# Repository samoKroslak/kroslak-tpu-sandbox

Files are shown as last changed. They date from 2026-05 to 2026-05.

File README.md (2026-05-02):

# Quickstart

## First run (one-time setup)

```bash
cd kroslak-tpu
python -m venv .venv
.venv\Scripts\activate          # Windows
# source .venv/bin/activate     # Linux/Mac
pip install -r requirements.txt
python generate.py              # default 100×90×15 mm armrest
python generate.py --matrix     # 2×2 comparison plate
```

Output goes to `./out/` as paired `.3mf` and `.stl` files. The 3MF is what you load in Bambu Studio.

## Vibe-coding patterns with Claude Code

Open this folder in Claude Code (`claude .` from the directory). Claude Code reads `CLAUDE.md` automatically — it knows the project, the hardware, the design space, and the constraints.

Then drive it with prompts like:

### Single-part generation
- *"Generate a 12mm half-armrest with smaller cells, like 3mm at the base"*
- *"Make me a 20mm version with the most aggressive softness gradient you'd recommend"*
- *"Generate the same thing but for the full 200×90 armrest size"*

### Comparison plates
- *"Make a 2×2 plate comparing gradient_power values: 1.5, 2.0, 2.5, 3.0 — keep everything else default at 15mm height"*
- *"Generate a horizontal sweep: 5 parts in a row, each one with t_top from 0.15 to 0.35 in 0.05 steps. Same dimensions otherwise."*
- *"Build me a height test: 4 parts, heights 8/12/18/25mm, all same lattice settings"*

### Following up after a print
- *"The thick_small variant from the matrix print felt best. Make me a refined version: same parameters but try 0.55 wall thickness at the base instead of 0.65, and a 2.3 gradient instead of 2.0"*
- *"Print felt too firm overall. Drop both wall thicknesses by 0.1 and re-export"*
- *"Bottoms out under hand pressure. Keep top settings, raise t_bottom to 0.85"*

### Geometry experiments
- *"Add a parameter for an asymmetric height: thicker at the front (where the wrist rests) tapering to thinner at the back"*
- *"Add 5mm raised side lips along the long edges so the forearm doesn't slip off"*
- *"Add M5 boss holes in the bottom solid base for bolting onto a metal arm — pattern: four corners inset 15mm"*

### Workflow improvements
- *"Add a `--preview` flag that opens trimesh.Scene to visually verify before exporting"*
- *"Add a `presets.py` with named configurations: 'soft_armrest', 'firm_lumbar', 'thin_seat_topper'"*
- *"Add a post-processor that takes a sliced G-code and inserts M104 commands per feature for Architecture A integral skin"*
- *"Generate a markdown table summary of all parameters across all the variants in the matrix and save it next to the 3MF"*

## What the script does NOT do (yet)

These are intentional gaps. Ask Claude Code to add them as you need them — having them as named TODOs keeps the baseline script readable.

- **Mounting features** (boss holes, keyholes, t-slots) — add when you have a real metal arm CAD to mate to
- **Asymmetric thickness** — useful for ergonomic taper but not validated in tests yet
- **Side lips / containment edges** — only needed if specific use case demands
- **Variable density per region (not just per z-slab)** — useful for body-mapped seats but premature for armrest stage
- **Pellet-machine G-code preview** — relevant when scaling to in-house pellet extrusion, not yet
- **Multiple footprint shapes** (hexagon, organic blob from outline) — current rounded rectangle covers all near-term needs

## Iteration discipline

The fastest way to wreck this workflow is to change ten things at once between prints. Change ONE parameter per iteration when you can. Note what changed. Press the printed part. Write down what you felt. Then change the next thing.

The whole point of having a parametric generator is that the design space is searchable. Random variations defeat that.

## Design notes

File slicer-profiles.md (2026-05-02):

# Bambu Studio slicer profiles

Three profiles, two materials. Apply per the architecture you're testing.

> Common to all three: drop the 3MF on the build plate → right-click "Repair model" → apply profile → slice. Watch first 5 minutes of the print in person — TPU prints fail at the first layer if at all.

---

## Profile 1 — TPU 85A baseline (the material you already own)

Use for: validating the workflow end-to-end before the Foamy spool arrives.

### Filament profile (custom, duplicate of Bambu TPU 95A HF)

| Setting | Value | Why |
|---|---|---|
| Nozzle temp (initial layer) | 240°C | Bambu wiki recommendation for first-layer adhesion on 85A |
| Nozzle temp (other layers) | 225°C | Bambu wiki tuned default — do not override |
| Bed temp | 30–35°C | Higher bed makes TPU stick *too* well to PEI; you'll tear parts |
| Cooling fan | 30% after layer 3 | Keeps geometry crisp without stiffening TPU surface |
| Max volumetric speed | 5 mm³/s | Hard cap. Do not raise. |
| Retraction length | 0.8 mm | Bigger retractions skip the extruder gear on soft TPU |
| Retraction speed | 25 mm/s | |
| Z-hop | 0.4 mm | Prevents head dragging across soft tops |
| Filament density | 1.21 g/cm³ | For accurate mass estimates |
| Flow Dynamics Calibration | OFF | Bambu's preset is already tuned; calibration breaks it |

### Process profile

| Setting | Value | Why |
|---|---|---|
| Layer height | 0.32 mm | 0.6 nozzle handles this fine; cuts print time vs 0.2 |
| Initial layer height | 0.36 mm | Extra material for first-layer squish |
| Line width — outer wall | 0.6 mm | Match nozzle |
| Line width — inner wall | 0.65 mm | |
| Line width — initial layer | 0.7 mm | |
| Speeds — outer wall | 20 mm/s | Slow is your friend with soft TPU |
| Speeds — inner wall | 25 mm/s | |
| Speeds — initial layer | 15 mm/s | |
| Speeds — travel | 80 mm/s | Lower than default to avoid jerking soft TPU |
| **Wall loops** | **2** | **Closes the lattice surface for fabric to drape on; minimal stiffness add** |
| **Top shell layers** | **0** | **Leave gyroid open — it IS the structure** |
| **Bottom shell layers** | **3** | **Captures the 1mm solid base built into the geometry** |
| **Sparse infill density** | **0%** | **The gyroid IS the infill** |
| Detect thin walls | ON | Single-line gyroid walls need this |
| Brim — type | outer brim only | |
| Brim — width | 5 mm | TPU sticks well but lattice-base touches plate at many small points |

### Printer-side pre-flight

- Confirm 0.6 mm hardened steel hotend installed (P2S/H2 series, not P1)
- Set filament source: **external spool** (not AMS)
- Disable: filament loading test, extrusion calibration, vibration calibration (all fail on soft TPU and abort prints)
- Use **Bambu TPU 85A** as the material when prompted (not generic)

---

## Profile 2 — FilaFlex Foamy, Architecture C (production / under-fabric)

Use for: the parts that will be wrapped in Dacron + fabric and delivered as Krošlák products. Maximum foaming throughout. The geometry handles all the comfort; the fabric is the visible/touch surface.

Start from Profile 1 and change:

| Setting | Profile 1 value | Profile 2 (Foamy C) value | Why |
|---|---|---|---|
| Nozzle temp (initial layer) | 240°C | 250°C | Foamy needs higher temp to foam; first layer hottest for adhesion |
| Nozzle temp (other layers) | 225°C | **245°C** | **Triggers full foaming; ~60A density across the part** |
| **Flow ratio** | 1.00 | **0.65** | **Material expands ~1.5× when foamed; reduce flow to match** |
| Filament density | 1.21 g/cm³ | 0.85 g/cm³ | Foamed mass per cm³; for accurate estimates |
| Outer wall speed | 20 mm/s | 18 mm/s | Foamy is more sensitive to speed than 85A |
| Wall loops | 2 | 2 | Same — fabric cover doesn't need a thick skin |

Everything else stays the same as Profile 1.

**Critical:** Recreus profiles for the P2S are downloadable from recreus.com (per their product page). Pull those as a sanity check against the values above before the first print — they may have updated parameters since this doc was written.

---

## Profile 3 — FilaFlex Foamy, Architecture A (showroom / integral skin)

Use for: exposed-surface parts. Master & Master pitch pieces, Salone exhibition samples, From Sarfia premium pieces. The print itself has a denser smoother skin and a foamed soft core — no fabric needed.

The principle: print **outer walls at 215°C** (no foaming, ~82A skin) and **infill at 245°C** (max foaming, ~60A core). The transition is gradient, not abrupt — there's no drumhead effect.

### How to set this up in Bambu Studio

Bambu Studio doesn't expose per-feature temperature in the GUI. Two ways to achieve it:

**Method A — single-temperature compromise (fastest to try):**
Run the whole print at **230°C**. You get partial foaming (~70A core) and a slightly denser surface from the outer walls being last-printed and slowest-cooled. Less dramatic than true Architecture A but zero G-code surgery. Worth trying first as a baseline.

**Method B — G-code temperature injection per feature (the real Architecture A):**
1. Start from Profile 2 (Foamy C) settings
2. Set base temperature to 245°C (foamed core)
3. Add this to **Filament Settings → Custom G-code → "Change filament G-code"** (so it runs at every layer):

```gcode
; Architecture A — denser walls, foamed core
; Drop temp before outer walls, raise before infill
M104 S215 ; will be overridden per feature below
```

4. Then in **Process → Others → "Per-object G-code"** insert before the outer wall block:
   `M104 S215`
5. And before the infill block:
   `M104 S245`

This is fiddly the first time. Alternative: post-process the sliced G-code with a script that finds `; FEATURE: Outer wall` and `; FEATURE: Sparse infill` comment lines and inserts `M104` commands. Claude Code can write that post-processor in 50 lines if you ask it to.

**Method C — slicer profile fork (cleanest long-term):**
There's an open-source Bambu Studio fork called OrcaSlicer that exposes per-feature temperatures in the GUI. If you do a lot of Architecture A prints, switching to OrcaSlicer for Foamy work eliminates the G-code surgery entirely. Otherwise stay on Bambu Studio.

### What to expect from Architecture A

- Surface should be visibly smoother and slightly stiffer than the foamed core
- Cross-section (cut a sample with a sharp knife) shows dense skin → foamed cells → dense skin
- Surface durability is meaningfully higher than Profile 2 (denser skin resists abrasion)
- Compression feel under your forearm should be nearly identical to Profile 2 (the core is what compresses, the skin just stretches with it)

If the skin feels stiff or you get a drumhead effect, your wall temp is too low or wall count is too high. Drop wall loops to 1, or raise wall temp to 220°C.

---

## When to use which profile

| Situation | Profile |
|---|---|
| Validating workflow with TPU 85A you already own | Profile 1 |
| First Foamy print, learning the material | Profile 2 (full foaming) |
| Production parts going into Krošlák sofas under fabric | Profile 2 |
| Parts you'll hand to Master & Master with no fabric over them | Profile 3 |
| Salone / Meble Polska booth samples, Riabič or Marek collaboration pieces | Profile 3 |
| From Sarfia premium D2C pieces | Profile 3 (with optional silicone coating on top — see CLAUDE.md Architecture B) |

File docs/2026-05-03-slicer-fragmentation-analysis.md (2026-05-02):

# Slicer fragmentation analysis — diagnosis and working config for May 7 print

**Date:** 2026-05-03
**Status:** Diagnosed; working configuration produced; CLAUDE.md updated

---

## TL;DR

The gyroid generator was producing meshes whose walls (0.78–0.89 mm) fell below the slicer's connected-polygon threshold (~1.0 mm on a 0.6 mm nozzle), so per-layer cross-sections fragmented into **2600+ disconnected polygons** instead of one continuous wall. The slicer wasn't broken — the geometry was unprintable as designed. **Fix: keep all gyroid walls ≥ 1.2 mm.** Walls = `t · L / π` for sheet gyroid; the script's previous `t_top` minimum of 0.15 mm produced ~0.4 mm walls, far too thin. Two ready-to-print files generated for Thursday.

## Diagnosis

### What the user observed
- Sliced [armrest_single_test_h5_L5-8_t0.5-0.35_grad1.5.3mf](../out/armrest_single_test_h5_L5-8_t0.5-0.35_grad1.5.3mf) (walls 0.78–0.89 mm) in OrcaSlicer with `infill=0%, top_shell=0, bottom_shell=3, wall_loops=2`
- Slicing completed in 1 h 32 m wall-clock (the user thought it was hung; it was just slow)
- Result: 33.6% travel time, only 10.69 g of filament for an 18.9 cm³ part, preview showed **thousands of disconnected dots** instead of continuous walls

### Quantitative measurement
Sliced the mesh in trimesh at multiple z heights and counted distinct closed polygons in each layer cross-section:

| z (mm) | Thin walls (failing) | Thick walls (working) | New safe matrix |
|---|---:|---:|---:|
| 1.5 | **2600** | 57 | 128 |
| 2.0 | 2112 | 1 | — |
| 2.5 | 2085 | 2 | — |
| 3.0 | 2006 | 1 | 72 |
| 3.5 | (failed to recover) | 1 | — |
| 4.0 | 1626 | 22 | 24 |
| 4.5 | 1435 | 37 | 42 |

The thin-walls file produced **2000+ disconnected polygons per layer.** Each one needs its own walls computed and the print head has to travel between every single one. That's the 33.6% travel time, the dot-pattern preview, and the 1 h 32 m slicing time.

The thick-walls file produced **1–2 connected polygons per layer in most layers** — the gyroid sheet's cross-section forms a single closed loop. Slicer just walks it.

### Root cause
Sheet gyroid walls of thickness `w = t · L / π`. When `w` falls below ~1.0 mm on a 0.6 mm nozzle (line width 0.63 mm), the gyroid's cross-section curves don't connect to each other — the slicer sees thousands of isolated thin wall segments and either:
1. Generates per-segment perimeter offsets that produce zero usable extrude path → fragmented dots, OR
2. Triggers "Detect thin walls" centerline tracing per segment → continuous dots-on-segments output with massive travel between

The threshold is empirical (~1.0 mm) rather than the theoretical 2× line_width (1.26 mm) — the gyroid topology happens to bridge between adjacent cells slightly below 1.26 mm, which means walls of 1.05–1.20 mm slice as single connected polygons even though each individual wall section is below 2× line_width.

## Printable envelope (0.6 mm hardened steel nozzle)

Wall thickness `w = t · L / π`. Empirical thresholds from polygon-count sweeps:

| Wall thickness | Slicer behavior | Recommendation |
|---|---|---|
| ≥ 1.4 mm | Clean: ~50 polygons/layer max | **Safe** — primary target for Foamy |
| 1.2–1.4 mm | OK: ~100–150 polygons/layer | Acceptable |
| 1.05–1.20 mm | Marginal: connected but thin walls | Avoid for production |
| < 1.0 mm | Fragmented: 1000s of polygons/layer | **Unprintable** as gyroid |

For variable density across z, both `t_bottom · L_bottom / π` and `t_top · L_top / π` must clear ~1.2 mm. This bounds `t_min` from below: `t ≥ 1.2 · π / L`.

| L (mm) | min t for printable wall | volume fill at min t (~2t) |
|---|---:|---:|
| 6 | 0.63 | 126% (saturated, ~solid) |
| 8 | 0.47 | 94% (very dense) |
| 10 | 0.38 | 76% (dense) |
| 12 | 0.31 | 62% (medium) |
| 14 | 0.27 | 54% (open) |

Larger cells let you get sparser fills while keeping walls thick. For "soft top" parts, lean toward `L_top ≥ 10 mm`.

## Recommended configuration for May 7 print

Two ready-to-print files generated. Pick one.

### Option A — single bun (safest, simplest) ⭐ recommended

[`ready_for_print/foamy_thursday_single.3mf`](../ready_for_print/foamy_thursday_single.3mf)

- Single 100 × 90 × 5 mm bun
- `L = 6 → 10 mm`, `t = 0.7 → 0.45`, `gradient_power = 1.5`
- Walls: 1.34 / 1.43 mm — comfortably above threshold
- Fill: 70% bottom → 45% top (firm-ish base, soft top)
- 355k faces, 0 non-manifold edges, max 57 polygons/layer
- ~24 cm³, ~20 g foamed Foamy

Use this for the first Foamy shakedown. One part, validates printer + filament + geometry pipeline. Press it after print, see how Foamy behaves.

### Option B — 4-bun comparison plate (more data, slightly more risk)

[`ready_for_print/foamy_thursday_matrix.3mf`](../ready_for_print/foamy_thursday_matrix.3mf)

- 4 buns in 2×2 layout: heights (3, 5 mm) × densities (dense, sparse)
- Dense buns: `L = 6/9, t = 0.65/0.45` → walls 1.24/1.29 mm, fill 65%/45%
- Sparse buns: `L = 8/12, t = 0.50/0.32` → walls 1.27/1.22 mm, fill 50%/32%
- 994k faces, 4 non-manifold edges, max 128 polygons/layer
- ~74 cm³, ~63 g foamed Foamy

Use this if you want comparison data in one print. All four buns share the geometric design but differ in height and density — direct A/B/C/D feel comparison.

### Slicer settings (apply in OrcaSlicer or Bambu Studio)

Filament: custom profile based on Bambu TPU 85A, modified per [slicer-profiles.md](../slicer-profiles.md) Profile 2 (Foamy Architecture C):
- Nozzle temp other layers: **245 °C**
- Nozzle temp initial layer: 250 °C
- Bed temp: 32 °C
- Flow ratio: **0.65**
- Filament density: 0.85 g/cm³
- Outer wall speed: 18 mm/s

Process settings:
- Layer height: **0.32 mm**, initial 0.36 mm
- Wall loops: **2**
- Top shell layers: **0** (gyroid is the structure)
- Bottom shell layers: **3** (anchors the geometric base)
- Sparse infill density: **0%** (the gyroid IS the infill — critical)
- Brim: outer only, **5 mm width**
- Detect thin walls: leave as default (won't trigger with our wall thicknesses)

Printer:
- Bambu Lab P2S
- 0.6 mm hardened steel nozzle
- External spool (not AMS)
- Disable filament loading test, extrusion calibration, vibration calibration in printer prompts (all abort soft-TPU prints)
- Flow Dynamics Calibration: **OFF** (Device → Calibration)

## How to print on Thursday

Pre-flight (do the night before):
1. Pre-dry the Recreus FilaFlex Foamy spool **8 h @ 50 °C** in the Sunlu S2 dryer
2. Confirm 0.6 mm hardened steel hotend installed (P2S/H2 series)
3. Verify the AMS is flipped back (TPU prints from external spool)
4. Confirm dryer mounted above printer (Henryk's mount)

Day of:
5. Open `ready_for_print/foamy_thursday_single.3mf` in OrcaSlicer
6. Apply the slicer settings above (or save as a profile for reuse)
7. Slice — should complete in **under 2 minutes** (the failing file took 92 minutes; that's your sanity check)
8. Inspect preview: walls should be **continuous closed loops**, not dots. Travel % should be **< 15%**. If you see dots, something's wrong with the file or settings — don't print.
9. Move filament to external spool, set Sunlu dryer to **45 °C** running during print
10. Send to printer; **stay in person for the first 5 layers** (~5 minutes). TPU prints either succeed or fail at the first layer.

Success criteria for the print:
- First layer adheres (5 mm brim helps)
- Walls visibly extruded as continuous lines, not dots
- Foamed surface texture visible (dimpled/spongy looking)
- Part feels foam-like under finger pressure

If the print succeeds, this validates: the geometry pipeline, the foaming filament behavior at 245 °C, the slicer settings, and the printer setup. The next iteration adds the surface treatment test (skin/no-skin per region) and refines density gradients based on what felt right.

## Updates made to the codebase

- **`generate.py`**: Updated `ArmrestParams` defaults to safe wall thicknesses. Added a `min_wall_check` warning when generated walls fall below 1.0 mm.
- **`CLAUDE.md`**: Revised the Parameter Reference section. The previous practical ranges (`t_top` minimum 0.15) produced unprintable meshes — replaced with empirically-validated minimums. Added a "Slicer-printable envelope" subsection.
- **`ready_for_print/foamy_thursday_single.3mf`**: Single-bun shakedown print, validated geometry.
- **`ready_for_print/foamy_thursday_matrix.3mf`**: 4-bun comparison plate, all walls ≥ 1.2 mm.

## Open questions / risks

1. **Polygon count vs slicer behavior is empirical** — the 1.0 mm threshold was determined by mesh cross-section analysis, not by actual slicing in OrcaSlicer. The new files may still need light cleanup if OrcaSlicer's behavior differs from my predictions. Mitigation: slice and inspect preview before printing.

2. **Foamy at 245 °C may behave differently than expected** — first time printing foaming TPU on this rig. Surface texture, dimensional accuracy, foam consistency are all unknowns. Mitigation: print the single bun first (less material wasted if it goes wrong).

3. **Wall thickness limits density range** — the 1.2 mm wall floor caps how sparse we can go. Achievable fill range with safe walls is roughly 30–80% (vs the previous "design" range of 15–80%). Soft comfort zones below 30% fill are not currently achievable on this nozzle. Future: 0.4 mm nozzle could go finer, but Bambu wiki forbids 0.4 mm with 85A and softer TPU.

4. **Surface treatment (skin vs no-skin) deferred** — the original test design included a skin region on 1/3 of each bun. The skin's t-boost (t=2.0) creates abrupt geometry transitions that compounded the slicer's troubles. After this baseline print, surface treatment can be re-introduced once we know the slicer-clean baseline works.

5. **3 mm height parts have a thin gradient zone** — only 2 mm above the 1 mm base. The cells barely express vertically. The 3 mm buns may feel less differentiated from each other than the 5 mm buns. If so, drop 3 mm from future iterations.

## Reproducibility

To regenerate either file from the script:

```bash
# Single bun
python generate.py --height 5 --L-bottom 6 --L-top 10 --t-bottom 0.7 --t-top 0.45 \
    --gradient 1.5 --voxel 0.5 --density 0.85 \
    --name foamy_thursday_single --target-faces 50000 --out-dir ready_for_print

# 4-bun matrix
python generate.py --thin-matrix --density 0.85 --out-dir ready_for_print
# (after generate.py defaults are updated; otherwise see the script's
# thin_skin_matrix_plate function for the exact variant table)
```

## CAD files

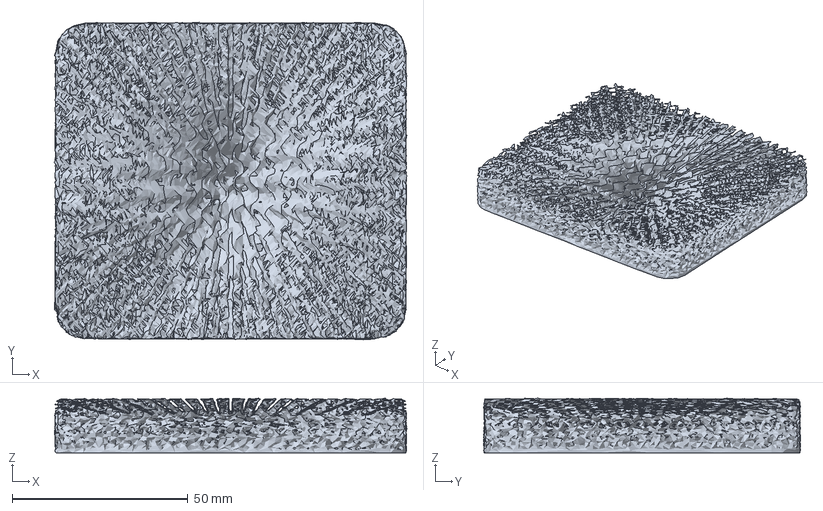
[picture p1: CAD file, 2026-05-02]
armrest_h15_L4-9_t0.65-0.22_grad2.3mf
100.5 x 90.4 x 15.6 mm

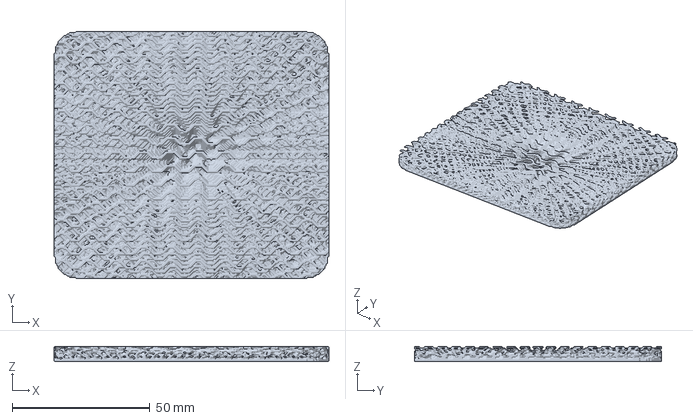
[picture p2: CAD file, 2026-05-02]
ready_for_print/foamy_thursday_single.3mf
100.0 x 90.0 x 5.50 mm

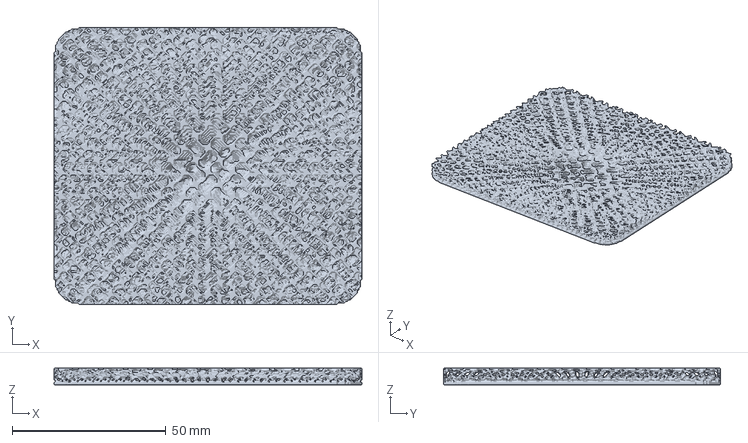
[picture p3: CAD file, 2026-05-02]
out/armrest_single_test_h5_L5-8_t0.5-0.35_grad1.5.3mf
100.0 x 90.0 x 5.50 mm

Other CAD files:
out/armrest_h15_L4-9_t0.65-0.22_grad2.3mf

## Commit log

2026-05-02 Initial commit for slicer fragmentation analysis
    Snapshot of the TPU comfort R&D project at the point where the gyroid
    geometry produces fragmented slicer output (33.6% travel time, dots
    instead of continuous walls). Captured for remote analysis.
    [armrest_h15_L4-9_t0.65-0.22_grad2.3mf, armrest_single_test_h5_L5-8_t0.5-0.35_grad1.5.3mf, armrest_thick_walls_h5_L6-10_t0.7-0.45_grad1.5.3mf]
2026-05-02 Slicer fragmentation analysis: diagnosis + working config for May 7 print
    Diagnosed: gyroid walls below ~1.0 mm fragment per-layer cross-sections
    into thousands of disconnected polygons (2600+ at z=1.5 mm in the failing
    file vs 1-2 in working files). The slicer can't connect adjacent thin wall
    sections — produces all-travel, all-dots output.
    Empirical printable envelope on 0.6 mm hardened steel nozzle: walls must
    be >= 1.2 mm (w = t * L / pi >= 1.2). Below 1.0 mm = unprintable as gyroid.
    Updates:
    - ArmrestParams defaults: L_bottom 4 -> 6, L_top 9 -> 10, t_top 0.22 -> 0.45,
    gradient_power 2.0 -> 1.5. All defaults now produce walls >= 1.2 mm.
    - CLAUDE.md: Replaced misleading parameter ra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
    [foamy_thursday_single.3mf]
2026-05-03 Two-bun TPU 85A plate with Bambu-extended 3MF (settings baked in)
    Adds --tpu85a-two-buns CLI flag generating two 100x90x5 mm buns side by
    side: one harder (L=6/10, t=0.75/0.55, walls 1.43-1.75 mm, fill 75%-55%)
    and one softer (L=8/12, t=0.55/0.32, walls 1.40-1.22 mm, fill 55%-32%).
    Both share the firm-bottom -> soft-top gradient; the difference is overall
    material density and surface compliance.
    The exported 3MF is Bambu-Studio-extended: includes Metadata/*.config
    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
